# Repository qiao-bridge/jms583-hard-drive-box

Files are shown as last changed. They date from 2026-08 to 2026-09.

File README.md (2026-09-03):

# JMS583 硬盘盒

> 基于 JMS583 主控的 M.2 NVMe 固态硬盘盒开源项目，采用「硬盘盒 + M.2 固态」的组合形式，**顺序读取速度可达 700MB/s**，兼顾大容量与高速读写。




- **嘉立创开源硬件平台**：https://oshwhub.com/qiao_wen/jms583-based-hard-disk-box
- **Gitee 仓库**：https://gitee.com/qiao-wenguo/jms583-hard-drive-box

---

## 目录

- [项目简介](#项目简介)
- [特性](#特性)
- [硬件架构](#硬件架构)
- [实物展示](#实物展示)
  - [整体效果](#整体效果)
  - [速度测试](#速度测试)
- [实物拼装](#实物拼装)
  - [所需材料](#所需材料)
  - [速度测试](#装配步骤)
- [快速开始](#快速开始)
- [固件说明](#固件说明)
  - [JMS583固件](#JMS583固件)
  - [STC8G1K08A固件](#STC8G1K08A固件)
- [目录结构](#目录结构)
- [开源许可](#开源许可)
- [致谢与参考](#致谢与参考)

---

## 项目简介

传统的移动存储介质，容量与速度难以兼得。本项目以 **JMicron JMS583** USB 3.1 Gen 2 转 PCIe/NVMe 桥接芯片为核心，搭配一块 **M.2 固态硬盘**，实现一个：
- **大容量**：支持 NVMe M.2 SSD，轻松扩展到数 TB；
- **高速度**：USB 3.1 Gen 2（10Gbps）接口，实测**顺序读取约 700MB/s**；
- **扩展性**：比成品硬盘盒更灵活，加入stc8g单片驱动内置风扇，便于学习与二次开发。
- **主要面向**：需要大容量高速移动存储的场景。 
>——锅包肉

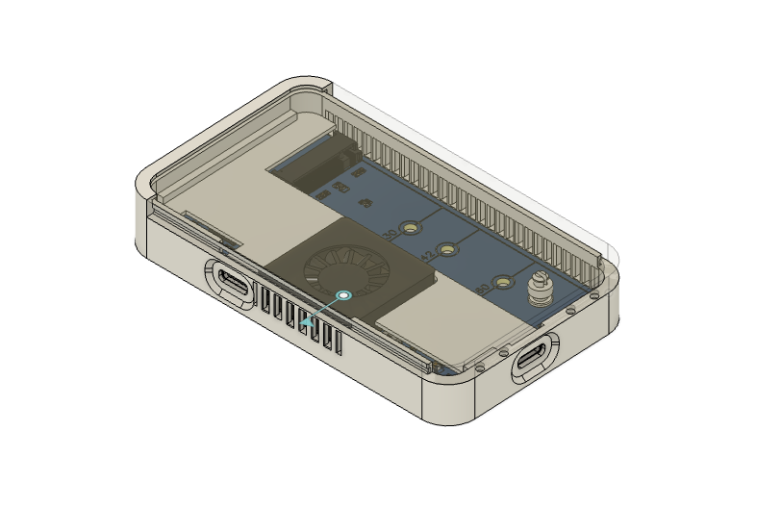
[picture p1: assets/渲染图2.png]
产品整体效果

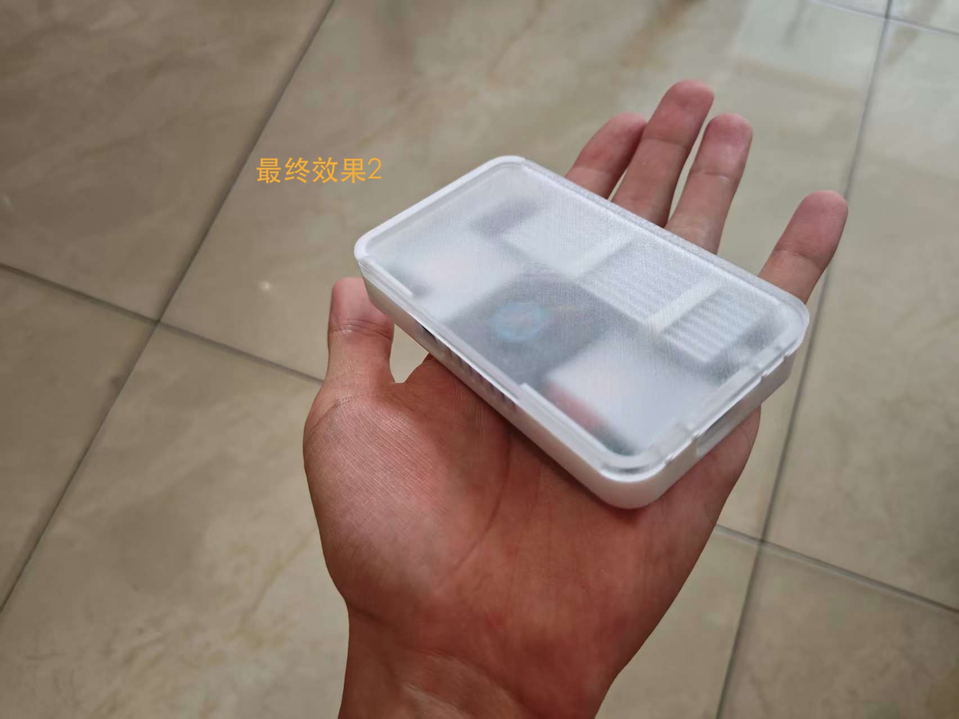
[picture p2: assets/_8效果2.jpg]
成品效果3

> 成品整体效果（PCB + 外壳 + M.2 固态装配完成）。

详见 [特性一览](#特性) 与 [实物展示](#实物展示)。

---

## 特性

- 🚀 **主控芯片**：JMicron JMS583（USB 3.1 Gen 2 to NVMe Bridge）
- 💾 **存储接口**：M.2 M-Key（NVMe）
- 🔌 **上行接口**：USB Type-C（USB 3.1 Gen 2，10Gbps）
- ⚡ **性能**：顺序读取可达 **700MB/s**（受 SSD 与线缆质量影响）
- 🧊 **散热**：PCB 预留散热片，内置涡轮风扇，外壳开散热窗
- 🔧 **固件**：提供JMS583固件与 stc8g的驱动
- 📦 **外壳**：3D 打印，装配即用

---

## 硬件架构

系统由 **USB 接口 → JMS583 桥接 → M.2 固态** 三部分组成，整体框图如下：

```
┌─────────────────────────────────────────────┐
│                 硬盘盒 PCB                    │
│                                             │
│   Type-C (数据) ──► JMS583 ──► M.2 NVMe SSD │
│                        │                    │
│   Type-C (供电) ──► 电源管理                 │
│                                             │
│                    STC8G1K08A ◄── 风扇/LED  │
│                                             │
└─────────────────────────────────────────────┘
```

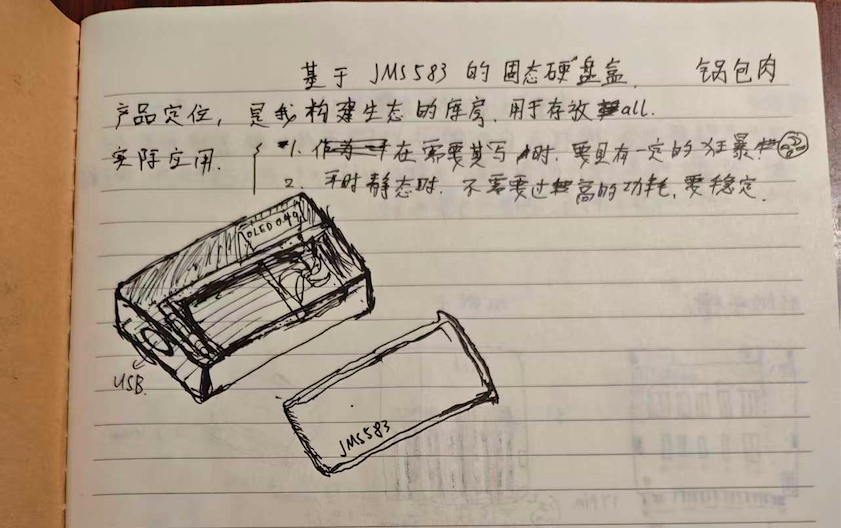
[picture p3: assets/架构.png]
硬件架构图

> 思路结构。

> 详见 [`hardware/`](./hardware) 目录下的原理图、PCB 源文件（如立创EDA）。

---

## 实物展示

### 整体效果
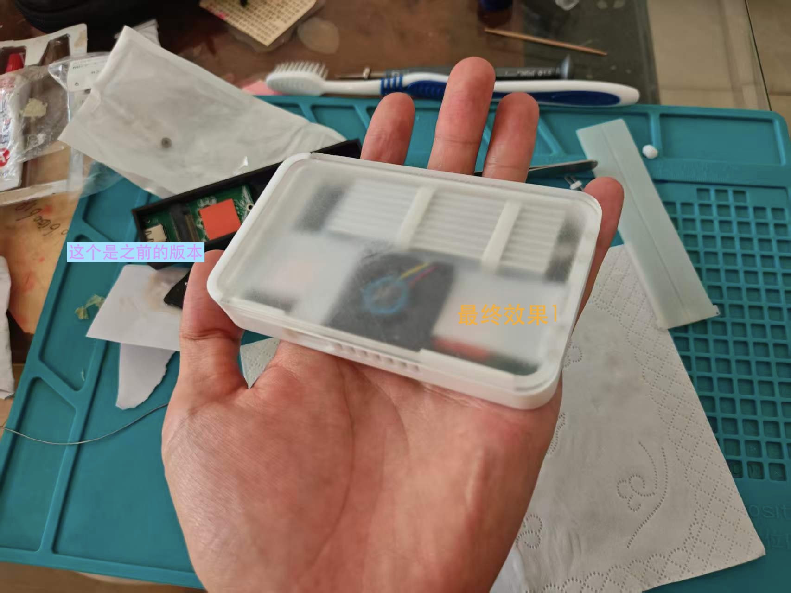
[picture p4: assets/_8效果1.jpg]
成品效果 1

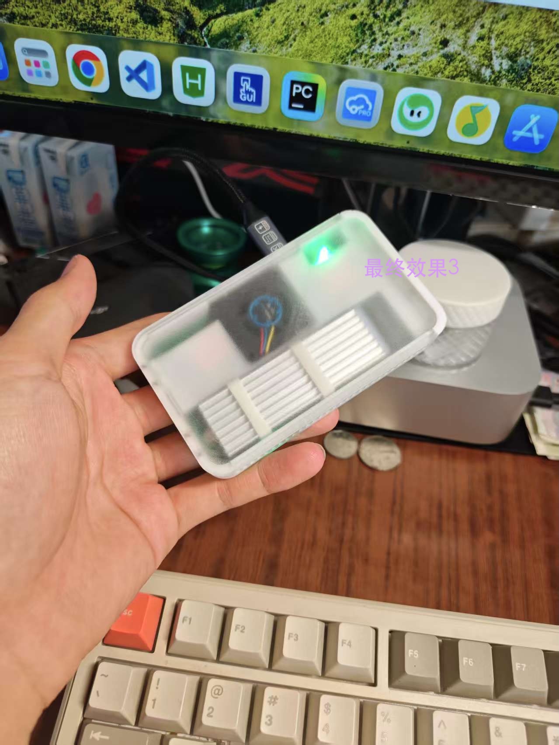
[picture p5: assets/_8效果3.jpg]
成品效果 2


> 分解 / 爆炸动画见 [`分解效果.mp4`](assets/分解效果.mp4)。

### 速度测试

在 Windows / macOS 下实测，顺序读取可达约 **700MB/s**：

#### CrystalDiskMark（Windows）

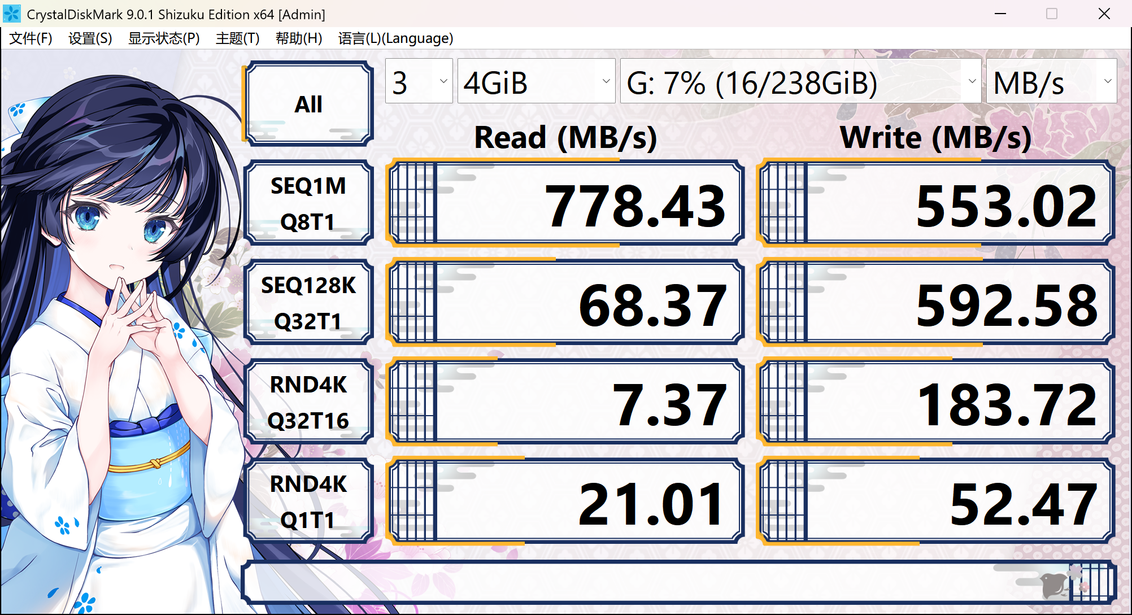
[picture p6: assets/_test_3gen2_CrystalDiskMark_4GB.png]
CrystalDiskMark USB3 Gen2 4GB 测试

> USB 3.1 Gen 2 模式下 4GB 测试块结果, 顺序读取约 700MB/s。

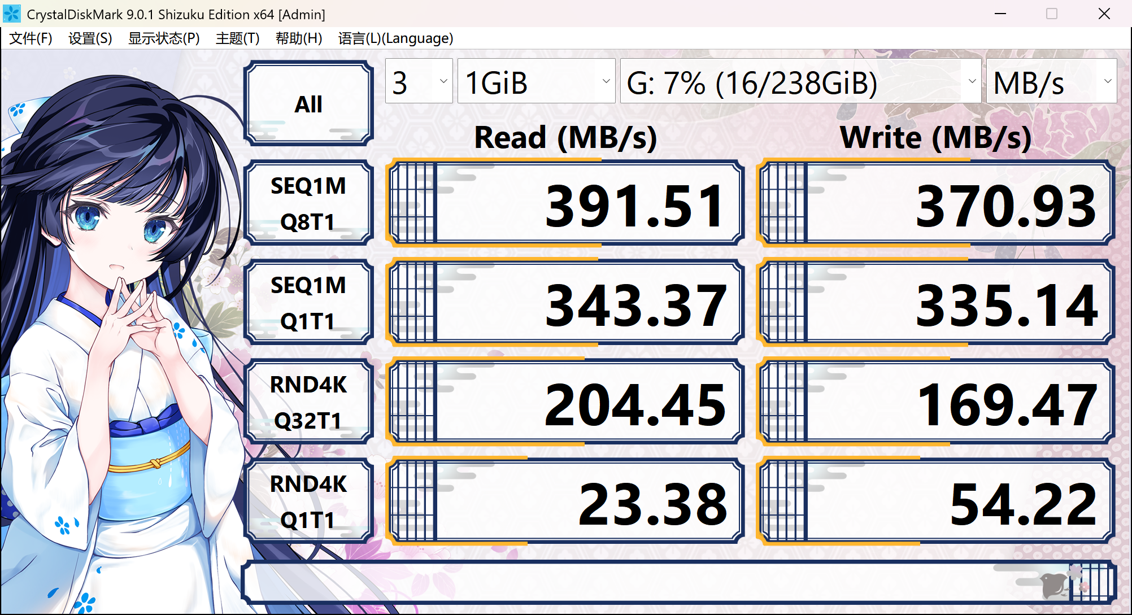
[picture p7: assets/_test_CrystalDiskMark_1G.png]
CrystalDiskMark 1GB 测试

> 1GB 测试块，顺序读取约 400MB/s。

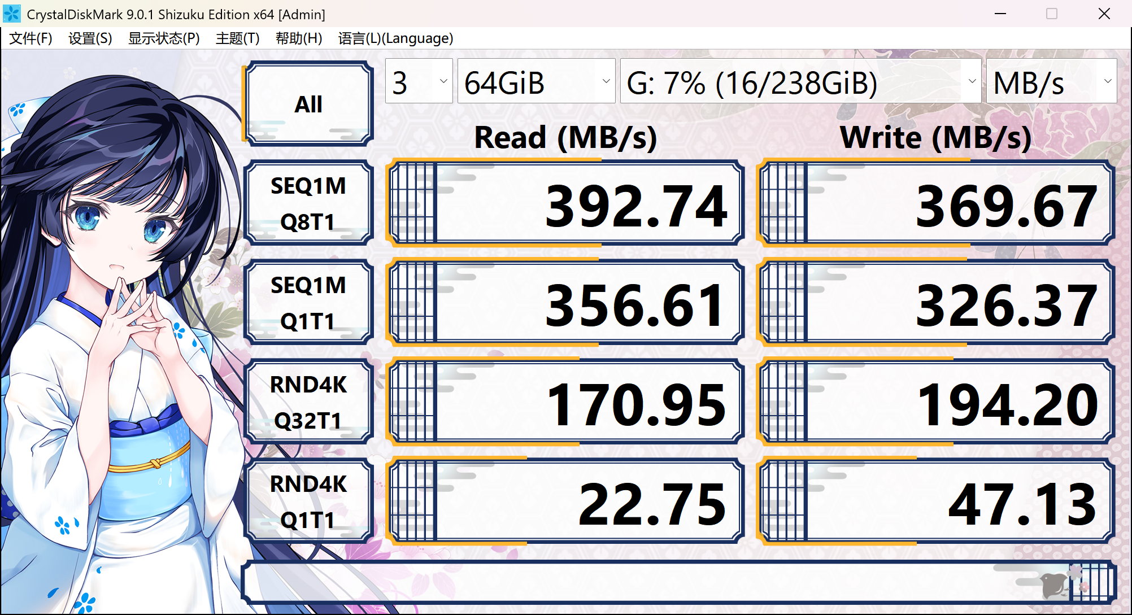
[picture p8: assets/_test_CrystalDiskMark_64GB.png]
CrystalDiskMark 64GB 测试

> 64GB 大文件测试，验证持续读写稳定性。

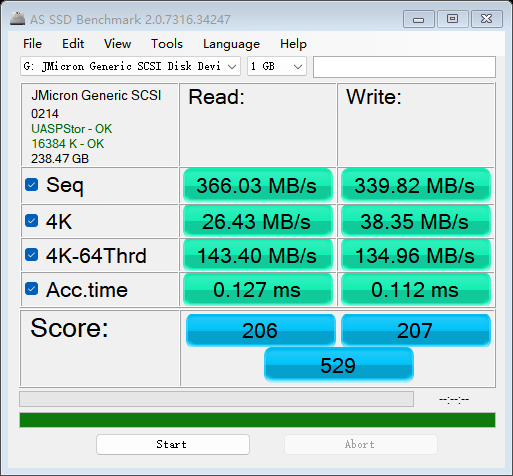
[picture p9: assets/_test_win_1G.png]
SSD benchmark 1G

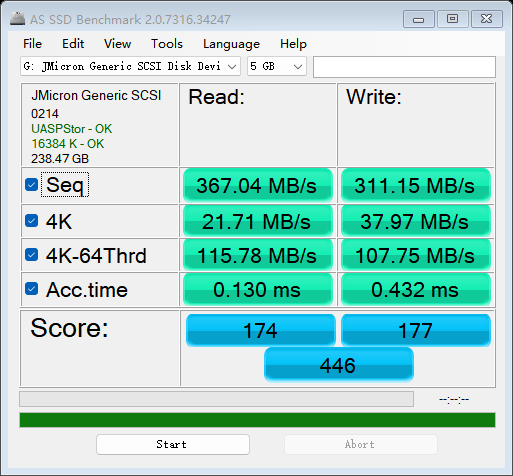
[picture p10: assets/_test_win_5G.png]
SSD benchmark 5G

> benchmark，验证持续读写稳定性。

#### Blackmagic Disk Speed Test（macOS）

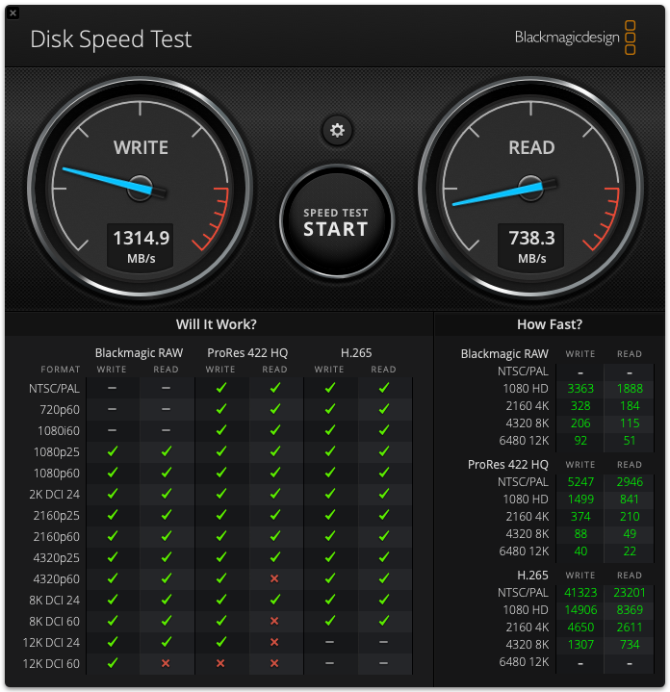
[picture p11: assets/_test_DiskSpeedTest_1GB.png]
DiskSpeedTest 1GB

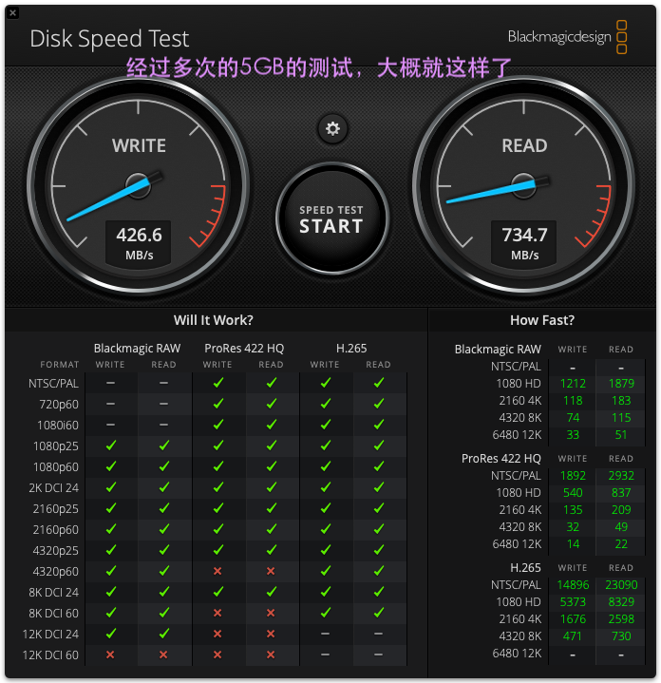
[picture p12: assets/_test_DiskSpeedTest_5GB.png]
DiskSpeedTest 5GB

> macOS 下使用 Blackmagic Disk Speed Test 测试（1GB / 5GB 测试文件）。

#### macOS 下实际文件拷贝测试

- 读取 17GB 文件实测约 30 秒：[`_test_mac实际读取17GB文件测试_大概过30s.mov`](assets/_test_mac实际读取17GB文件测试_大概过30s.mov)
- 写入 17GB 文件实测约 52 秒：[`_test_mac实际写入17GB文件测试_大概过52s.mov`](assets/_test_mac实际写入17GB文件测试_大概过52s.mov)

> 实际数值以你的 SSD 型号、线缆质量与主机接口为准。

---

## 实物拼装

### 所需材料

- [ ] 焊接好的 PCB（见 [焊接风扇](#焊接风扇)）
- [ ] JMS583 主控及外围元器件
- [ ] M.2 NVMe 固态硬盘一块
- [ ] USB Type-C 数据线（**需支持 USB 3.1 Gen 2 / 10Gbps**，普通 2.0 线缆无法达到标称速度）
- [ ] 外壳
- [ ] 导热垫 / 散热片

### 装配步骤
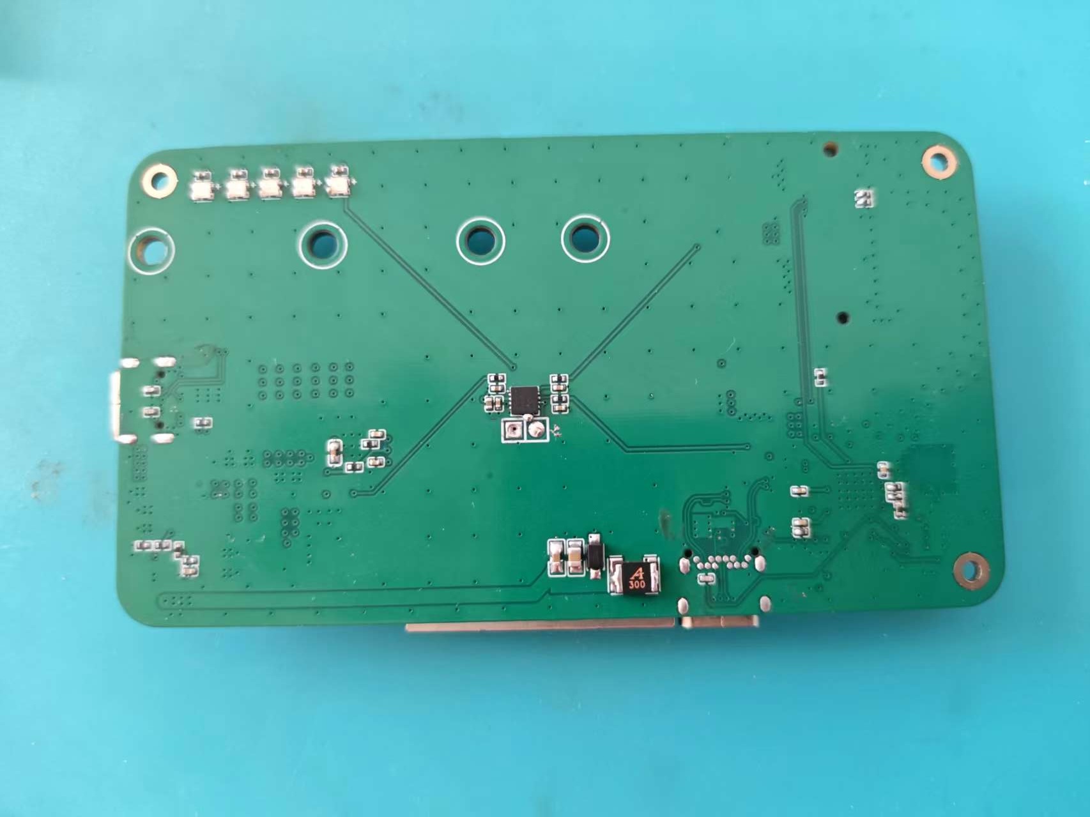
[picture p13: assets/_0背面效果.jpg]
背面效果


> 装配流程分解：

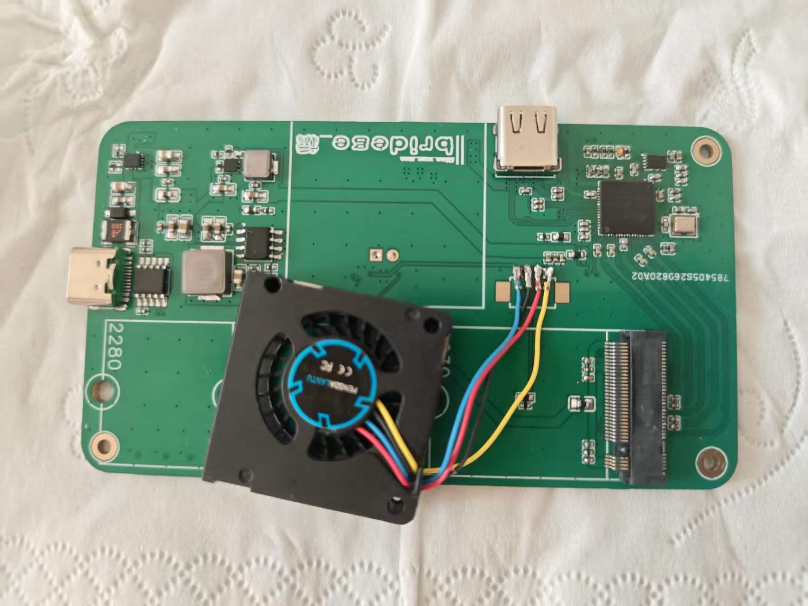
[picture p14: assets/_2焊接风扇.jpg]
焊接风扇

> 焊接风扇与散热相关元件。

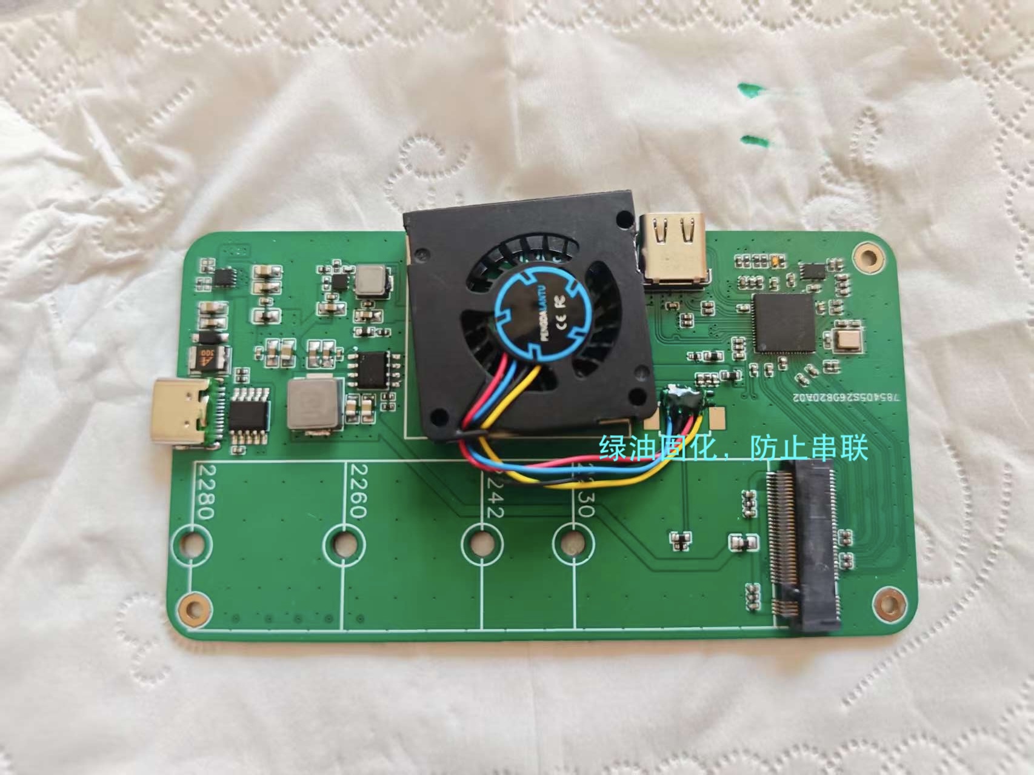
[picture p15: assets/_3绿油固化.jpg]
绿油固化

> PCB 绿油固化处理。

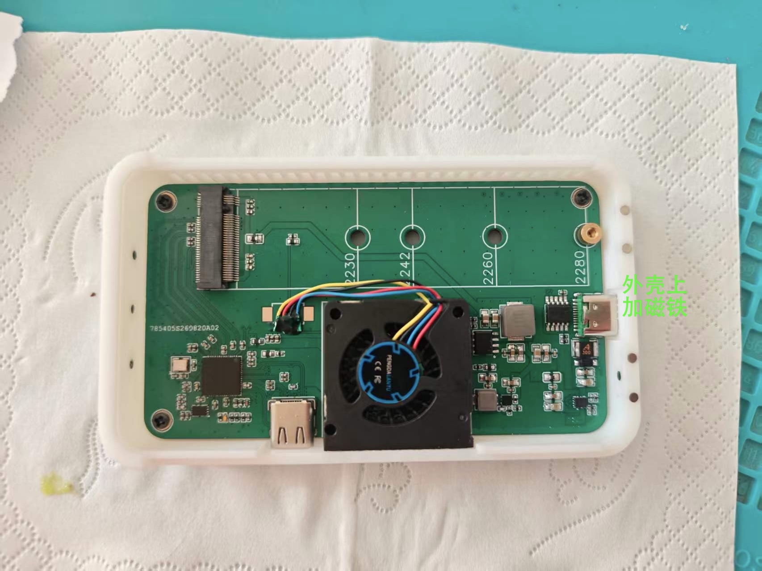
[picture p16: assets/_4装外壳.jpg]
装入外壳

> 将 PCB 装入外壳并固定。

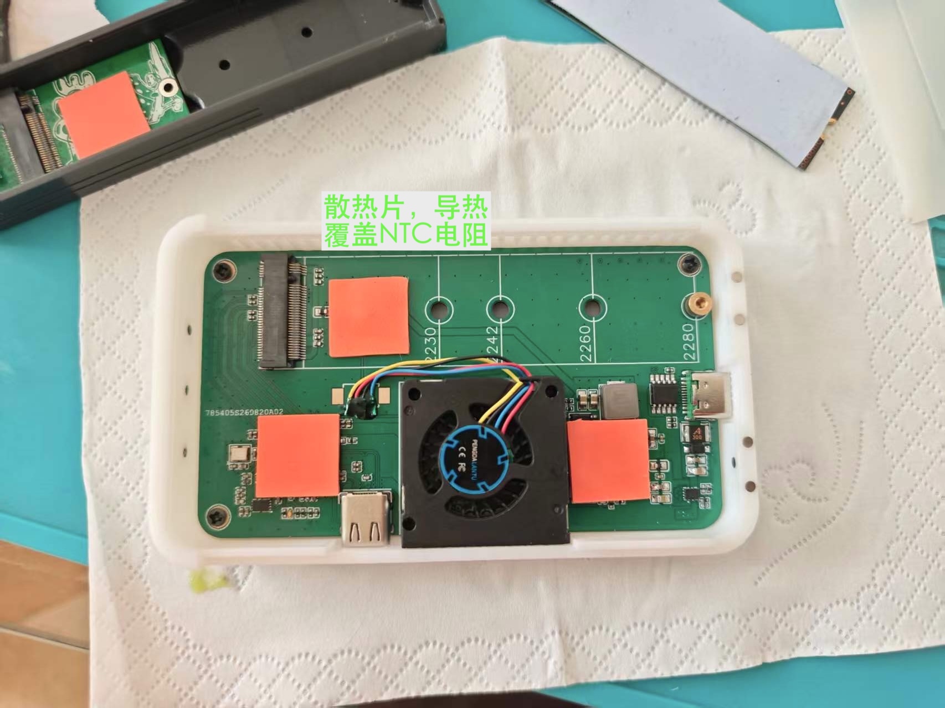
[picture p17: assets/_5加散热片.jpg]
安装散热片

> 在主控 / 颗粒面贴导热垫并加装散热片。

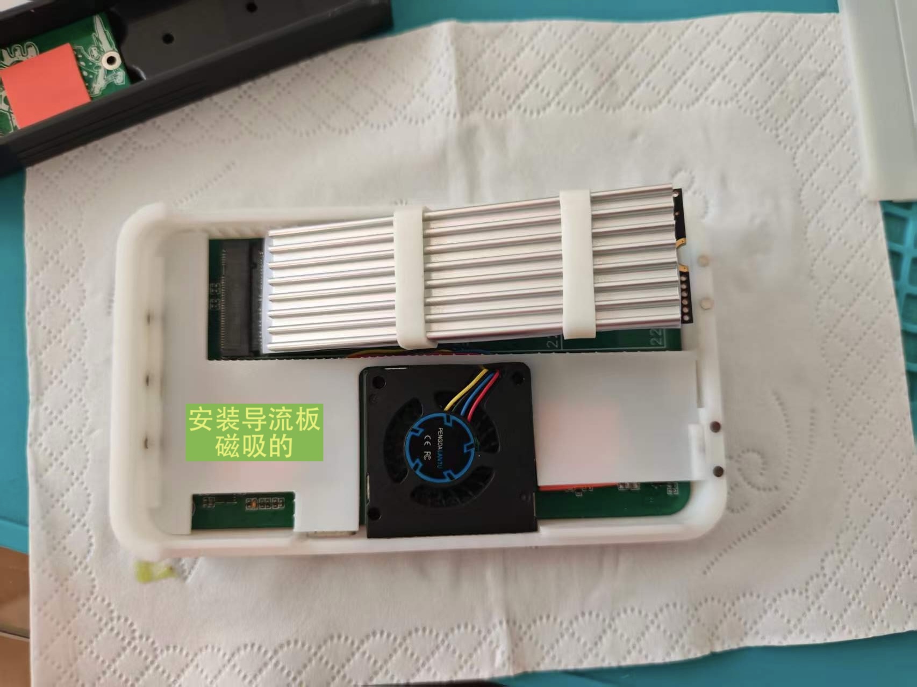
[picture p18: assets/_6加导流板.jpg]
加装导流板

> 加装导流板，优化风道。

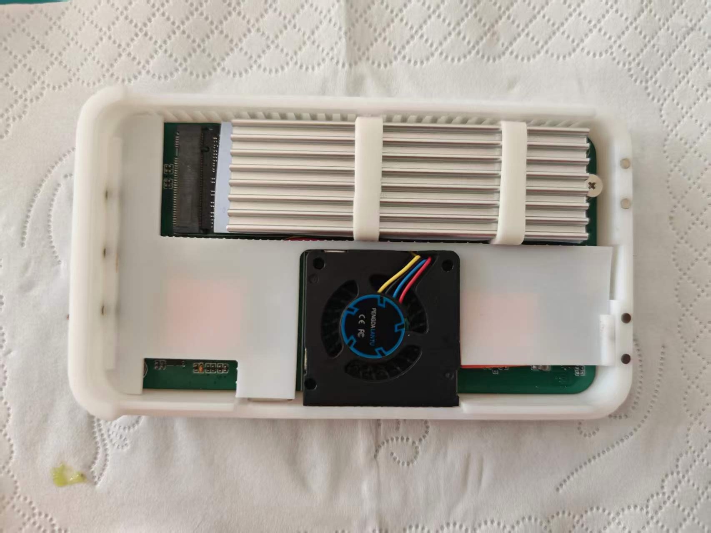
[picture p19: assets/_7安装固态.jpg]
安装固态

> 安装 M.2 固态硬盘。

---

## 快速开始

### 制作 PCB

见 [`hardware/`](./hardware) 目录，包含原理图、PCB 源文件与 Gerber。推荐使用嘉立创等平台打样：

1. 直接打印Gerber文件；
2. 按默认工艺下单（板厚 1.6mm，沉金或喷锡均可）；
3. 收到板子后按 BOM 焊接。

### 打印 / 制作外壳

见 [`enclosure/`](./enclosure) 目录，包含可打印文件stl以及源文件。

- 3D 打印建议：下壳和导流板材料随意，上盖使用半透明（8001）或透明；
- 装配时先放安装m2*1的磁铁，用螺丝（m2*3或M2*4）固定pcb，最后是上盖。
- 外壳模型渲染见 [项目简介](#项目简介)（[`渲染图.PNG`](assets/渲染图2.PNG)），成品效果见 [实物展示](#实物展示)（[`_8效果1.jpg`](assets/_8效果1.jpg) 等）。

### 焊接元器件

- 推荐使用**热风枪 + 锡膏**焊接 JMS583（QFN）、M.2接口、typec、小元件；
- Type-C 等密脚元件可用烙铁 + 助焊剂；
- 焊接完成后**先检查短路**（尤其电源与地），再上电。

---

## 固件说明

> 本项目包含 **两套固件**，分别对应两个主控：
> 1. **JMS583** 桥接芯片固件（USB ↔ NVMe 桥接逻辑）
> 2. **STC8G1K08A** 单片机固件（风扇 / 呼吸灯 / adc等控制逻辑）

### JMS583固件
- **作用**：实现 USB 3.2 Gen 2 与 PCIe NVMe 之间的协议桥接。
- **文件**：见仓库 `firmware/jms583/` 目录。
- **升级方式**：通常通过厂商工具FwUpdateTool.exe `firmware/jms583/tools`通过 USB 接口在线升级。
- **注意**：
  - 在刷写的时候看看有没有Flash的信息，jms583支持挺多厂商的，如果没有flash的信息，烧录会是比啊，检查是不是焊接问题（包括那个QFN的焊接）或者是换个芯片。
  - 固件升级过程与本仓库的 STC8G1K08A 烧录是**两个独立流程**，请勿混淆。

### STC8G1K08A固件
- **作用**：控制散热风扇、WS2812呼吸灯、adc等辅助逻辑。
- **开发环境**：Keil C51。
- **烧录方式**：通过串口（UART）连接 STC8G1K08A 的 **P3.0 (RxD) / P3.1 (TxD)** 引脚，使用 STC-ISP 工具烧录。
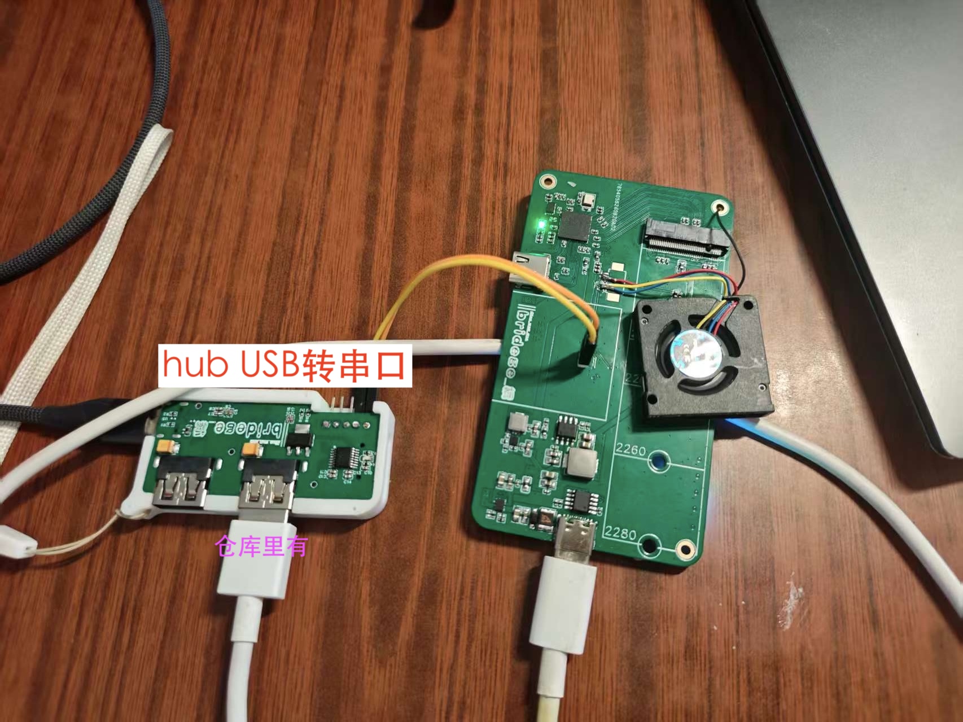
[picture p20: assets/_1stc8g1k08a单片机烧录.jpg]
STC8G1K08A 烧录
- **烧录要点**：stc8g的供电和串口的供电时同一路，见

---

## 目录结构

```
jms583硬盘盒/
├── Datasheet/   # JMS583 等芯片数据手册 (Datasheet)
├── assets/      # README 引用的图片资源（本文件所用配图）
├── docs/        # 补充文档（说明、规格、测试记录等）
├── enclosure/   # 外壳 3D 模型 / 加工图纸
├── firmware/    # 两种固件
├── hardware/    # 原理图、PCB 源文件与 Gerber
├── LICENSE      # GPL-3.0 许可证
└── README.md    # 本文档
```

---

## 许可证

本项目基于 **GNU General Public License v3.0** 开源，详见 [`LICENSE`](./LICENSE) 文件。

> 硬件设计（原理图、PCB）遵循相同的开源许可，允许个人与商业使用，但需保留署名并按 GPL 开源衍生作品。

## 致谢与参考

- [JMicron JMS583 产品页](https://www.jmicron.com/)
- [嘉立创开源硬件平台 - 本项目](https://oshwhub.com/qiao_wen/jms583-based-hard-disk-box)

---

> 本文档随项目持续更新。如发现错误或有改进建议，欢迎提 Issue / PR。
如发现错误或有改进建议，欢迎提 Issue / PR。

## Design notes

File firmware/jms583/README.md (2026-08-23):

###改固件使用的来自于https://oshwhub.com/aknice/jms583-demo

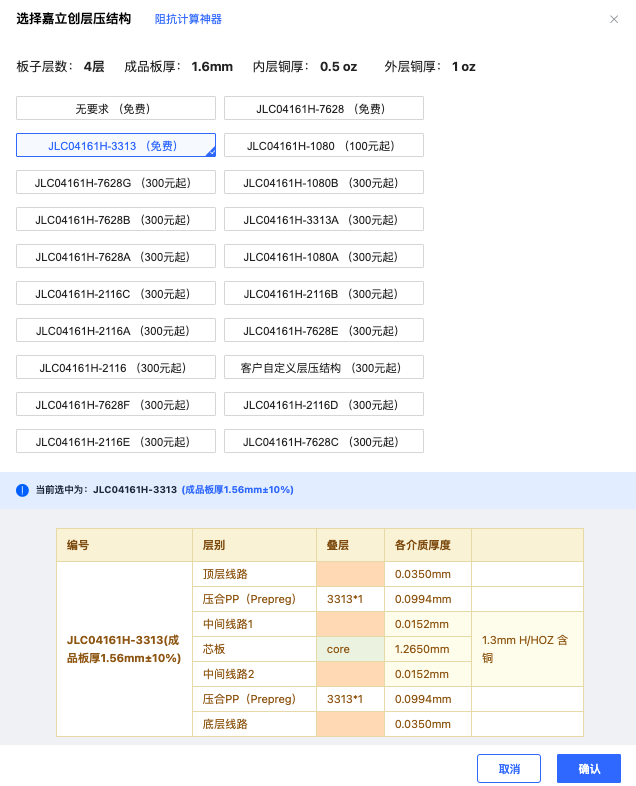
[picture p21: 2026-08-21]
docs/嘉立创压层选择.png

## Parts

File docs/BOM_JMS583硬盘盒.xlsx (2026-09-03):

No. | Quantity | Comment | Designator | Footprint | Value | Manufacturer Part | Manufacturer | Supplier Part | Supplier
1 | 45 | 100nF | C1,C2,C3,C6,C9,C15,C18,C22,C23,C26,C30,C34,C35,C36,C37,C38,C41,C42,C46,C48,C50,C51,C54,C55,C56,C57,C60,C61,C62,C63,C64,C67,C70,C74,C75,C77,C81,C82,C83,C84,C85,C86,C87,C88,C89 | C0402 | 100nF | HGC0402R5106M100NTEJ | Chinocera(华瓷) |  | LCSC
2 | 6 | 22uF | C4,C11,C13,C16,C32,C33 | C0805 | 22uF | HGC0805R5226M350NSLJ | Chinocera(华瓷) | C22367832 | LCSC
3 | 8 | 10uF | C5,C12,C14,C17,C24,C27,C28,C29 | C0805 | 10uF | HGC0805R5226M350NSLJ | Chinocera(华瓷) |  | LCSC
4 | 4 | 330pF | C7,C8,C19,C20 | C0402 | 330pF | HGC0402R5106M100NTEJ | Chinocera(华瓷) |  | LCSC
5 | 10 | 1uF | C10,C40,C43,C44,C47,C49,C66,C69,C73,C79 | C0402 | 1uF | HGC0402R5106M100NTEJ | Chinocera(华瓷) |  | LCSC
6 | 1 | 10nF | C21 | C0603 | 10nF | HGC0603R5106M350NTHJ | Chinocera(华瓷) |  | LCSC
7 | 1 | 22pF | C25 | C0402 | 22pF | HGC0402R5106M100NTEJ | Chinocera(华瓷) |  | LCSC
8 | 1 | 3.9nF | C31 | C0402 | 3.9nF | HGC0402R5106M100NTEJ | Chinocera(华瓷) |  | LCSC
9 | 8 | 10uF | C39,C45,C65,C68,C71,C72,C76,C80 | C0402 | 10uF | HGC0402R5106M100NTEJ | Chinocera(华瓷) |  | LCSC
10 | 4 | 220nF | C52,C53,C58,C59 | C0402 | 220nF | HGC0402R5106M100NTEJ | Chinocera(华瓷) |  | LCSC
11 | 1 | 15pF | C78 | C0402 | 15pF | CC0402JRNPO9BN200 | YAGEO(国巨) |  | LCSC
12 | 1 | M-key 3.2H（m.2固态接口）91302-32-067RDM | CN1 | CONN-SMD_91302-32-067RDM |  | 91302-32-067RDM | UMaxconn(友贸) | C1509730 | LCSC
13 | 1 | （可以不用，手焊，风扇接口座子，）SH-1.25-4AWT | CN2 | CONN-SMD_SH-1.25-4AWT |  | SH-1.25-4AWT | 深海电子 | C53260987 | LCSC
14 | 2 | （双向tvs）SMF5.0CA | D1,D2 | SOD-123FL_L2.7-W1.8-LS3.8-BI |  | SMF5.0CA | R+O(宏嘉诚) | C19077498 | LCSC
15 | 2 | （保险丝保持3A跳闸4A）SMD1812-300-12 | F1,F2 | F1812 |  | SMD1812-300-12 | R+O(宏嘉诚) | C46641166 | LCSC
16 | 1 | （磁珠4A）BLM21PG300SN1D | FB1 | L0805 | 30Ω | BLM21PG300SN1D | muRata(村田) | C16903 | LCSC
17 | 1 | （烧录排针2.54）A2541WV-2P | H1 | HDR-TH_P2.54-H-M_A2541WV-2P |  | A2541WV-2P | CJT(长江连接器) | C225477 | LCSC
18 | 1 | 2.2uH | L1 | IND-SMD_L4.4-W4.2 | 2.2uH | FXL0420-2R2-M | cjiang(长江微电) | C167206 | LCSC
19 | 1 | 10uH | L2 | IND-SMD_L7.3-W6.8 | 10uH | FXL0630-100-M | cjiang(长江微电) | C167223 | LCSC
20 | 1 | (磁珠2A）CBM160808U121T | L3 | L0603 |  | CBM160808U121T | FH(风华) | C62708 | LCSC
21 | 1 | (磁珠4A）CBM201209U121T | L4 | L0805 |  | CBM201209U121T | FH(风华) | C93624 | LCSC
22 | 1 | led_0402 | LED1 | LED-SMD_L1.0-W0.5_FC-F1005UGK |  | NCD0402G1 | 国星光电 | C130723 | LCSC
23 | 5 | WS2812B-2020-V6 | LED2,LED3,LED4,LED5,LED6 | LED-SMD_4P-L2.2-W2.0-P1.00_WS2815C-2020-4P |  | WS2812B-2020-V6 | worldsemi | C52917434 | LCSC
24 | 2 | 20kΩ | R1,R2 | R0402 | 20kΩ | THC02H1002BT | FH(风华) |  | LCSC
25 | 1 | 29.8kΩ | R3 | R0402 | 29.8kΩ | THC02H1002BT | FH(风华) |  | LCSC
26 | 5 | 100kΩ | R4,R11,R12,R14,R25 | R0402 | 100kΩ | THC02H1002BT | FH(风华) |  | LCSC
27 | 3 | 5kΩ | R5,R6,R8 | R0402 | 5kΩ | THC02H1002BT | FH(风华) |  | LCSC
28 | 9 | 10kΩ | R7,R18,R20,R32,R33,R34,R35,R36,R37 | R0402 | 10kΩ | THC02H1002BT | FH(风华) |  | LCSC
29 | 2 | 2kΩ | R9,R10 | R0402 | 2kΩ | THC02H1002BT | FH(风华) |  | LCSC
30 | 1 | 91kΩ | R13 | R0402 | 91kΩ | THC02H1002BT | FH(风华) |  | LCSC
31 | 1 | 6.8kΩ | R15 | R0402 | 6.8kΩ | THC02H1002BT | FH(风华) |  | LCSC
32 | 1 | 120kΩ | R16 | R0402 | 120kΩ | THC02H1002BT | FH(风华) |  | LCSC
33 | 1 | 26.1kΩ | R17 | R0402 | 26.1kΩ | THC02H1002BT | FH(风华) |  | LCSC
34 | 1 | 5.1kΩ | R19 | R0402 | 5.1kΩ | THC02H1002BT | FH(风华) |  | LCSC
35 | 1 | 12kΩ | R21 | R0402 | 12kΩ | THC02H1002BT | FH(风华) |  | LCSC
36 | 2 | 49.9Ω | R22,R23 | R0402 | 49.9Ω | THC02H1002BT | FH(风华) |  | LCSC
37 | 1 | 510kΩ | R24 | R0402 | 510kΩ | THC02H1002BT | FH(风华) |  | LCSC
38 | 1 | 200Ω | R26 | R0402 | 200Ω | THC02H1002BT | FH(风华) |  | LCSC
39 | 1 | 4.7kΩ | R27 | R0402 | 4.7kΩ | THC02H1002BT | FH(风华) |  | LCSC
40 | 1 | 200kΩ | R28 | R0402 | 200kΩ | THC02H1002BT | FH(风华) |  | LCSC
41 | 3 | (NTC热敏电阻)HNTC0603-104F3950FB | R29,R30,R31 | R0603 |  | HNTC0603-104F3950FB | R+O(宏嘉诚) | C49247668 | LCSC
42 | 1 | TPS2121RUXR | U1 | VQFN-HR-12_L2.5-W2.0-P0.50-BL |  | TPS2121RUXR | TI(德州仪器) | C485916 | LCSC
43 | 1 | CH224A | U2 | ESSOP-10_L4.9-W3.9-P1.0-LS6.0-TL-EP |  | CH224A | WCH(南京沁恒) | C42459160 | LCSC
44 | 1 | AP2953AS8PRG | U3 | ESOP-8_L4.9-W3.9-P1.27-LS6.0-BL-EP |  | AP2953AS8PRG | chipown(芯朋微电子) | C130334 | LCSC
45 | 1 | AP3428DNTR-G1 | U4 | U-DFN2020-6_L2.0-W2.0-P0.65-BL-EP-2 |  | AP3428DNTR-G1 | DIODES(美台) | C698228 | LCSC
46 | 1 | JMS583 | U5 | QFN-64_L8.0-W8.0-P0.40-TL-EP4.5 |  | JMS583 |  | C9900032798 | LCSC
47 | 1 | W25Q80DVUXIE | U6 | USON-8_L3.0-W2.0-P0.50-BL-EP_GD25QXX |  | W25Q80DVUXIE | Winbond(华邦) | C401667 | LCSC
49 | 1 | STC8G1K08A-36I-DFN8 | U11 | DFN-8_L3.0-W3.0-P0.50-BL-EP |  | STC8G1K08A-36I-DFN8 | STC | C915664 | LCSC
50 | 3 | M2螺丝：M2*3 | U12,U13,U14 | M2螺丝孔 |  |  |  |  | LCSC
51 | 1 | TYPE-C 24P QCHT | USB1 | TYPE-C-SMD_TYPE-C-24P-QCHT |  | TYPE-C 24P QCHT | SHOU HAN(首韩) | C456013 | LCSC
52 | 1 | KH-TYPE-C-16P | USB2 | USB-C-SMD_KH-TYPE-C-16P |  | KH-TYPE-C-16P | kinghelm(金航标) | C709357 | LCSC
53 | 1 | 25MHz | X1 | OSC-SMD_4P-L3.2-W2.5-BL | 25MHz | OT322525MJBA4SL | YXC(扬兴晶振) | C669088 | LCSC
54 | 最少20个，淘宝一起买 |  | 型号：直径2mm，厚度1mm

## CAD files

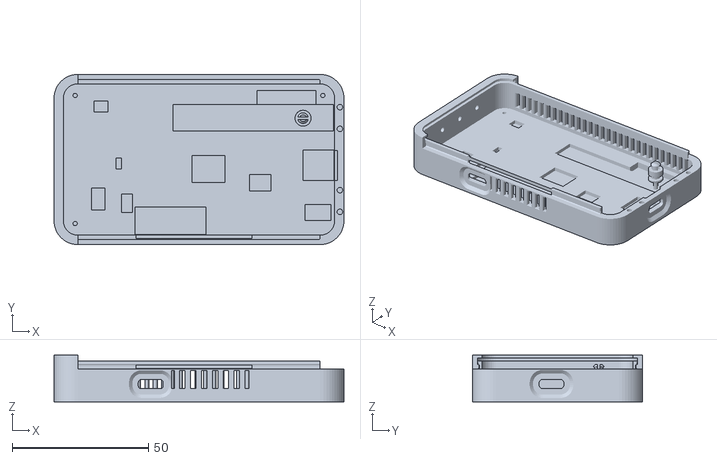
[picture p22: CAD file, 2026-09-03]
enclosure/print/下壳.stl
106.5 x 62.5 x 17.1

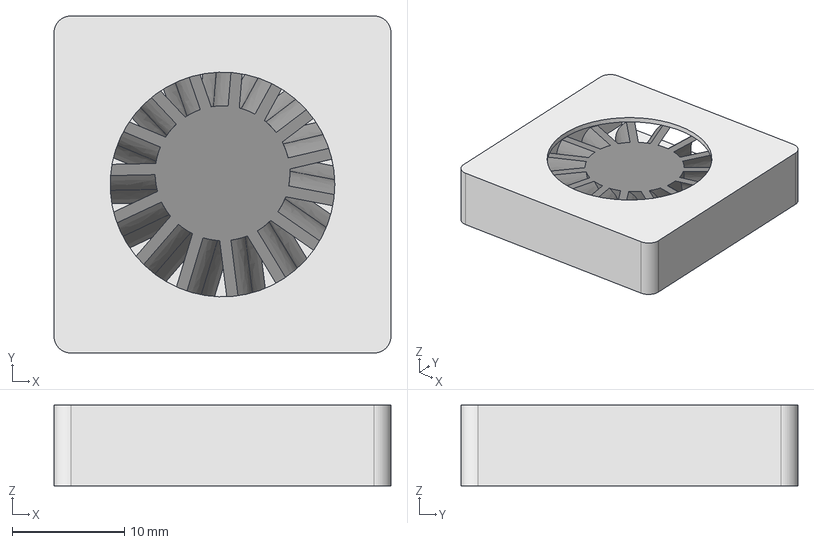
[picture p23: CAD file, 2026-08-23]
enclosure/source/3007涡轮风扇模型.step
30.0 x 30.0 x 7.20 mm
扇叶
涡轮风扇外壳

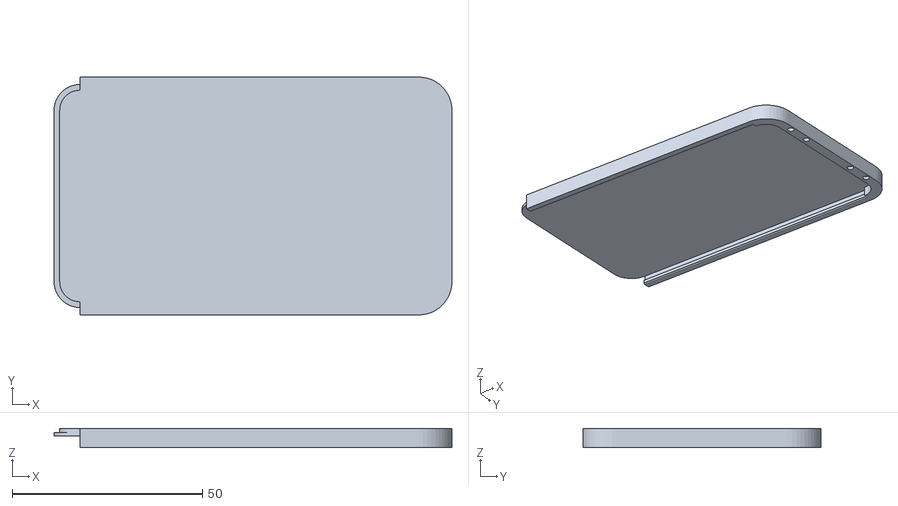
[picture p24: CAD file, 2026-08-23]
enclosure/print/上盖.stl
104.5 x 62.5 x 5.00

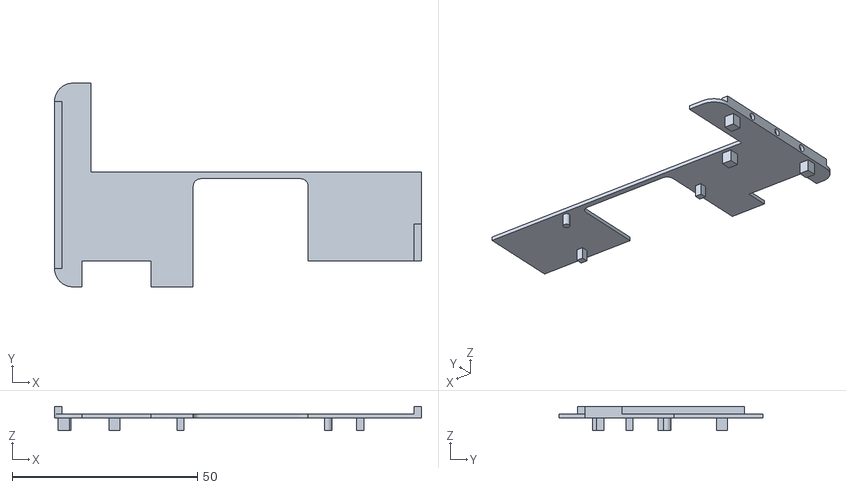
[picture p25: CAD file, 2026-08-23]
enclosure/print/导流板.stl
99.0 x 55.0 x 6.50

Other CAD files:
firmware/stc8g1k08a/project/Objects/main.obj
firmware/stc8g1k08a/project/Objects/stc8g_ws2812.obj
firmware/stc8g1k08a/project/Objects/stc8g_ntc_table.obj
firmware/stc8g1k08a/project/Objects/stc8g_delay.obj
firmware/stc8g1k08a/project/Objects/STARTUP.obj
firmware/stc8g1k08a/project/Objects/stc8g_gpio.obj
firmware/stc8g1k08a/project/Objects/stc8g_uart.obj
firmware/stc8g1k08a/project/Objects/stc8g_timer_pwm.obj
firmware/stc8g1k08a/project/Objects/stc8g_adc.obj
firmware/stc8g1k08a/project/Objects/stc8g_key.obj
firmware/stc8g1k08a/project/Objects/stc8g_pwm.obj
enclosure/source/JMS583硬盘盒外壳.f3z

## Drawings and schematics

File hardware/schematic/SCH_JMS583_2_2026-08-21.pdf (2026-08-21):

GND A12 RX2+ A11 RX2- A10 VBUS A9 SBU1 A8 D- A7 D+ A6 CC1 A5 VBUS A4 TX1- A3 TX1+ A2 GND A1

GND | GND

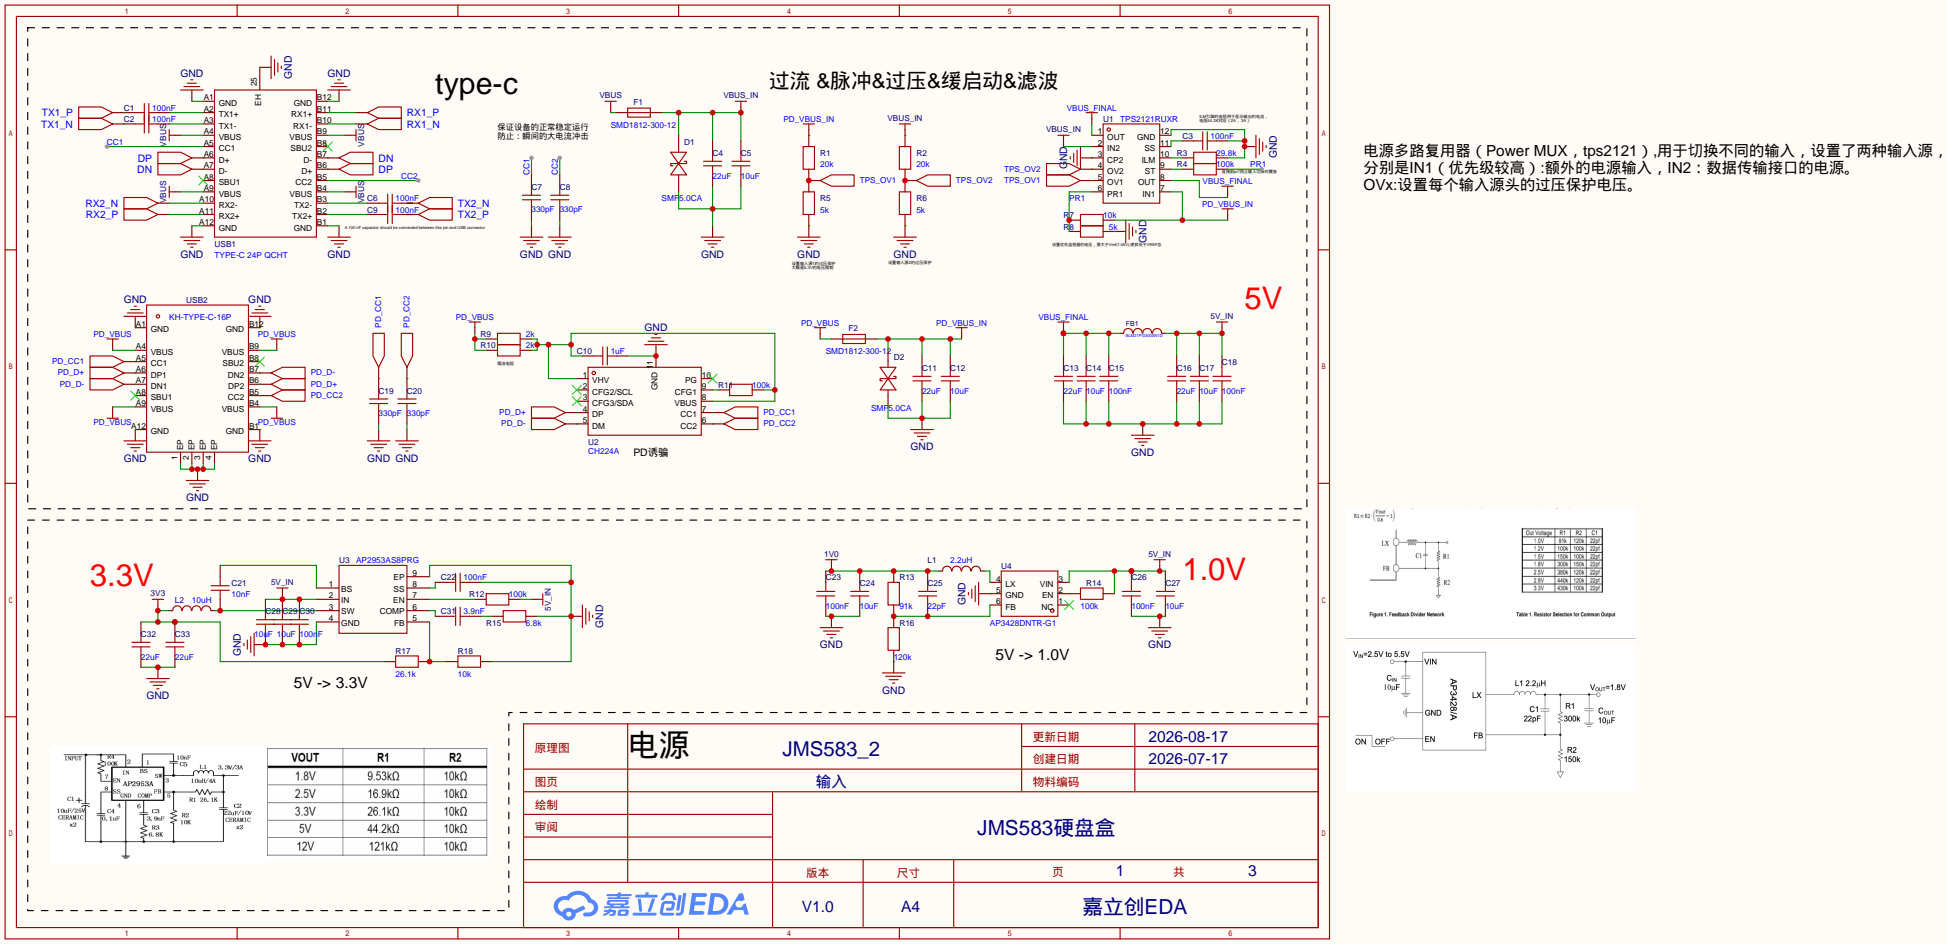
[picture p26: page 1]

过流 &脉冲&过压&缓启动&滤波

电源多路复用器（Power MUX，tps2121）,用于切换不同的输入，设置了两种输入源，
分别是IN1（优先级较高）:额外的电源输入，IN2：数据传输接口的电源。
OVx:设置每个输入源头的过压保护电压。

A 100 nF capacitor should be connected between this pin and USB connector

VCCO 32 P_AVDDL 33 P_RXN1 34 P_RXP1 35 P_AVDDL 36 P_TXN1 37 P_TXP1 38 REXT 39 P_AVDDL 40 P_RXN0 41 P_RXP0 42 P_AVDDL 43 P_TXN0 44 P_TXP0 45 C_AVDDL 46 P_CLKN 47 P_CLKP 48 P_AVDDL 49 XIN 50 XOUT 51 XAVDDH 52 VCCK 53 P_RSTN 54 P_CLKREQN 55 VCCO 56 GPIO12 57 MODE0/GPIO11 58 MODE1/GPIO10 59 TME 60 CC2 61 CC1 62 GND 63 LXO 64 EP 65

### GND

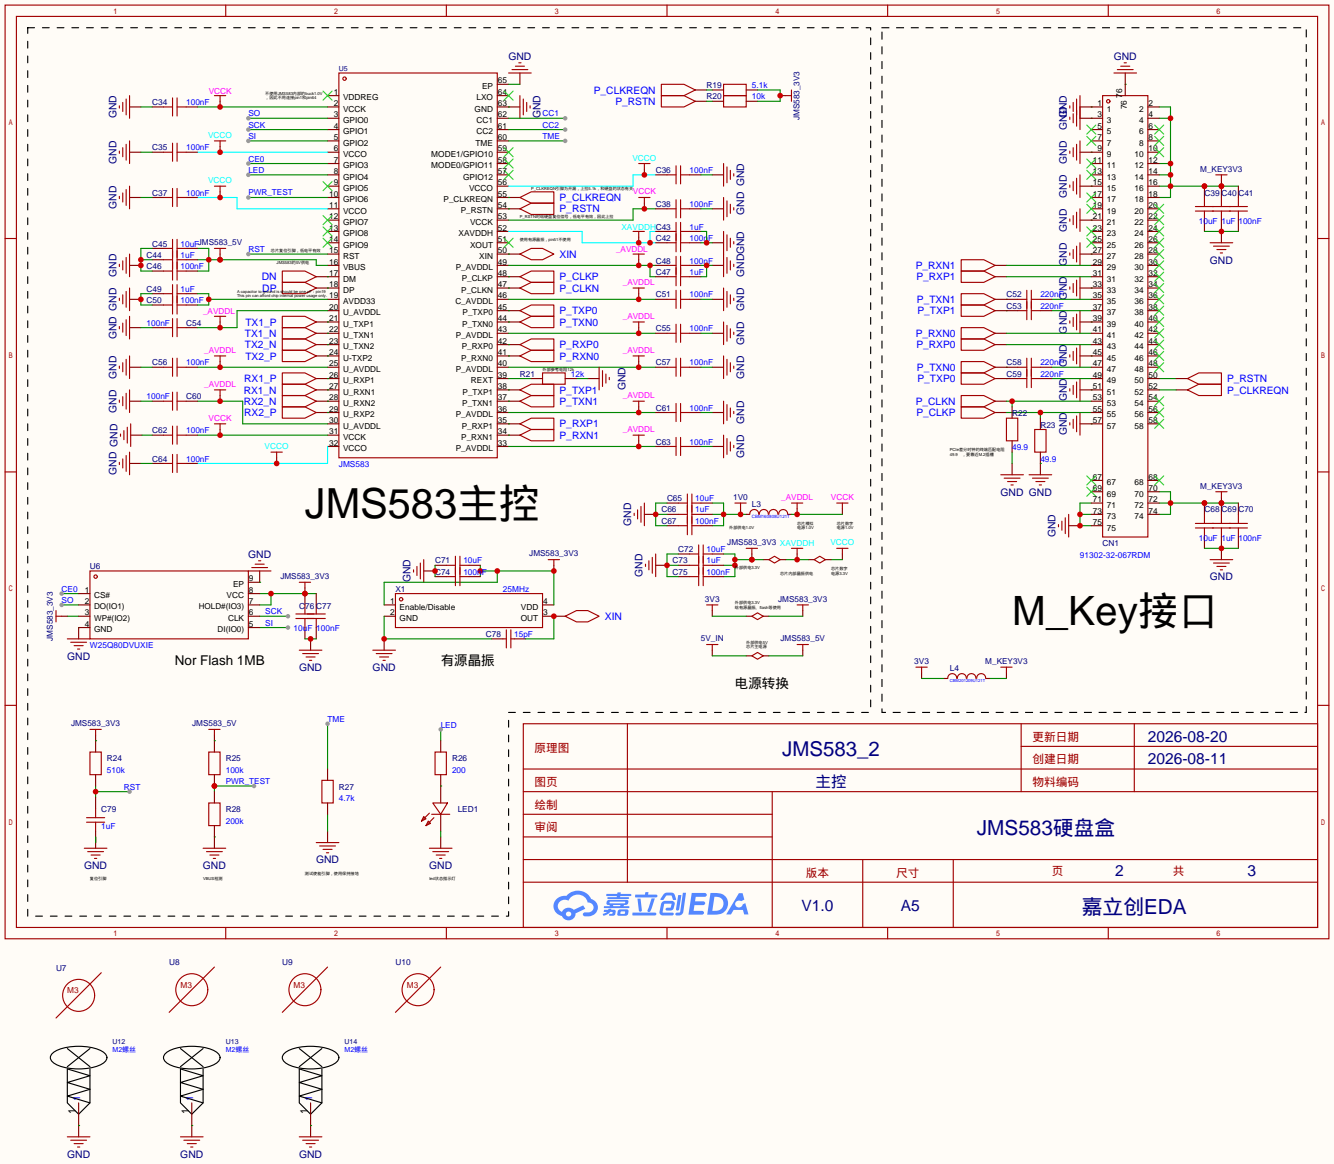
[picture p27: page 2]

GND GND GND GND

C66 | 1uF 100nF
C67

GND | GND

### GND

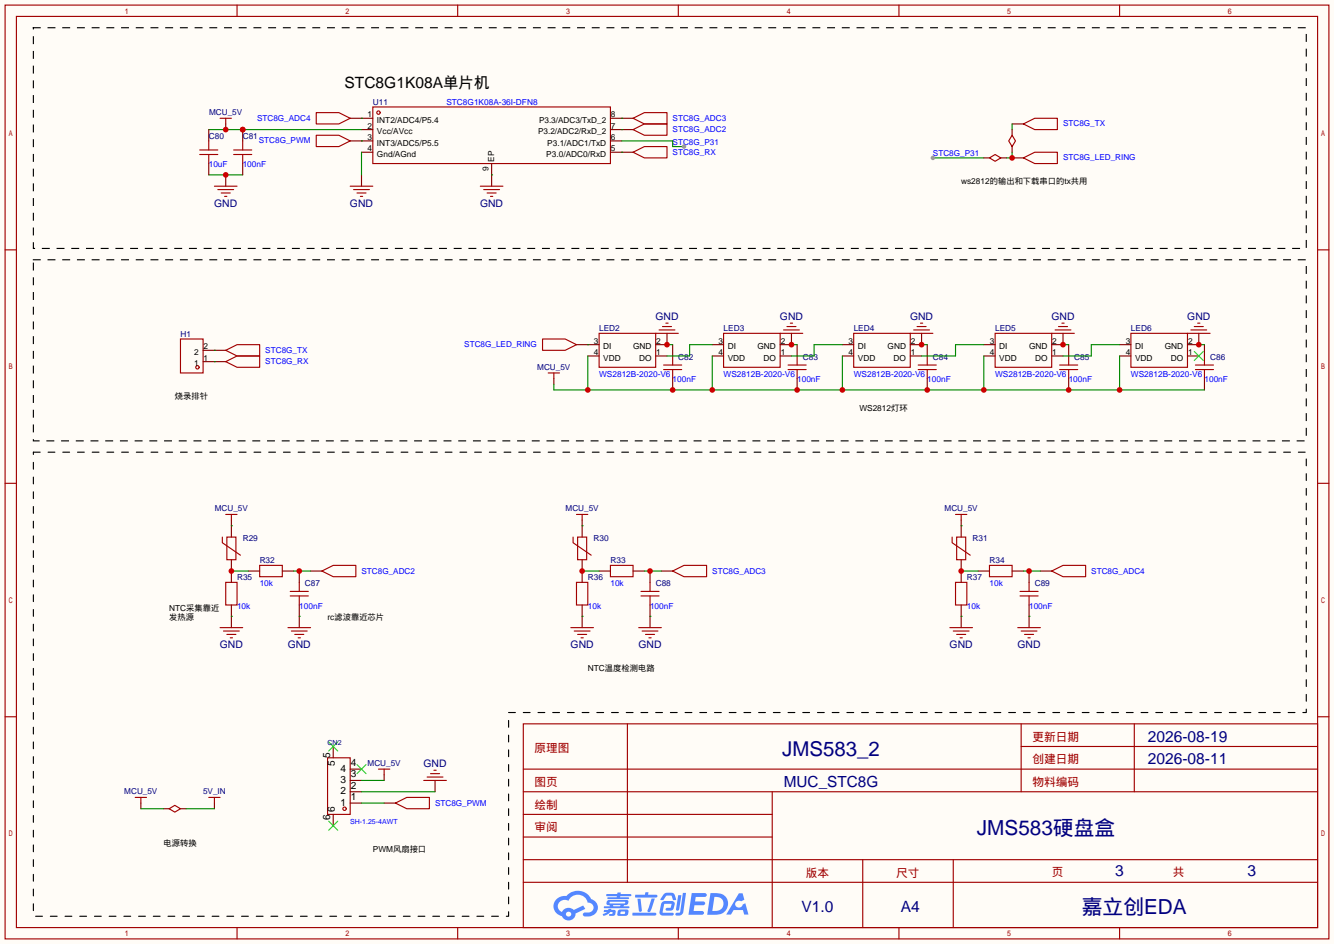
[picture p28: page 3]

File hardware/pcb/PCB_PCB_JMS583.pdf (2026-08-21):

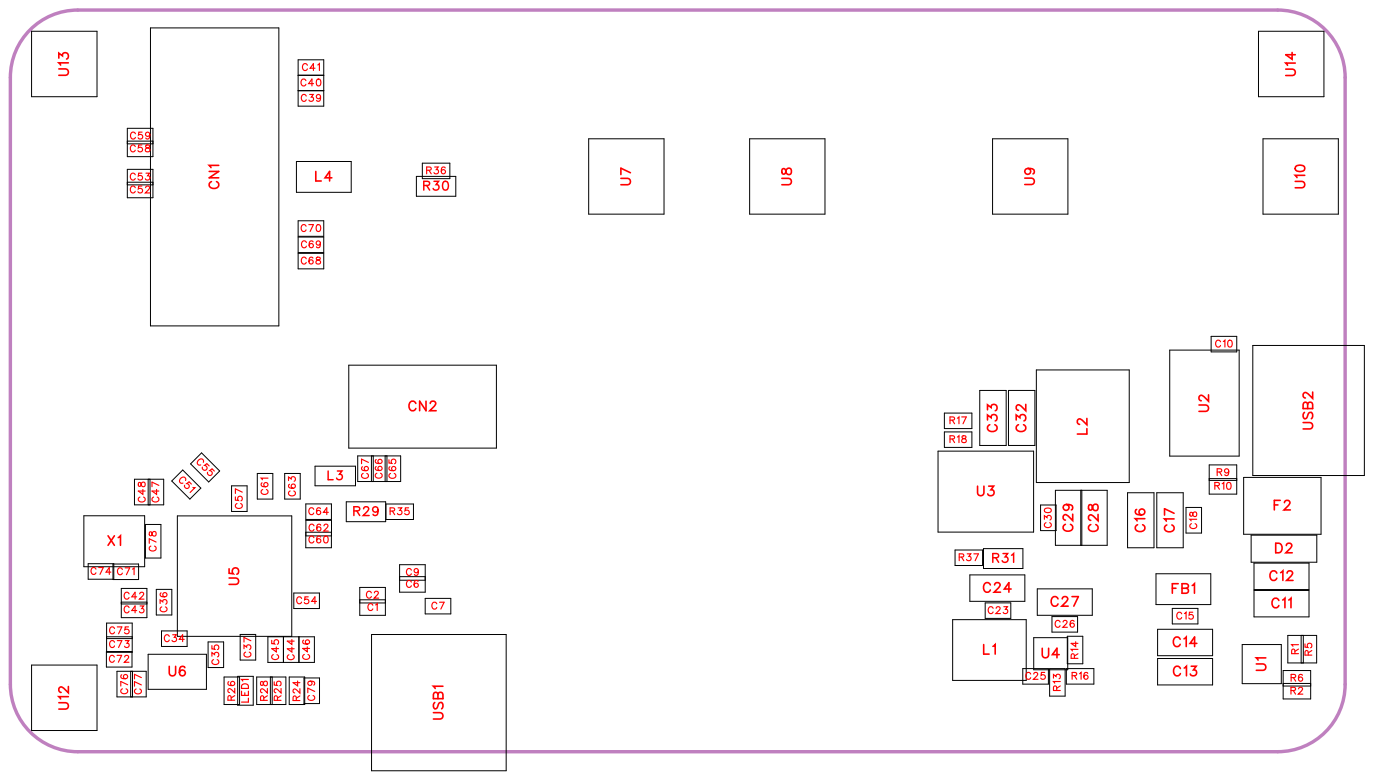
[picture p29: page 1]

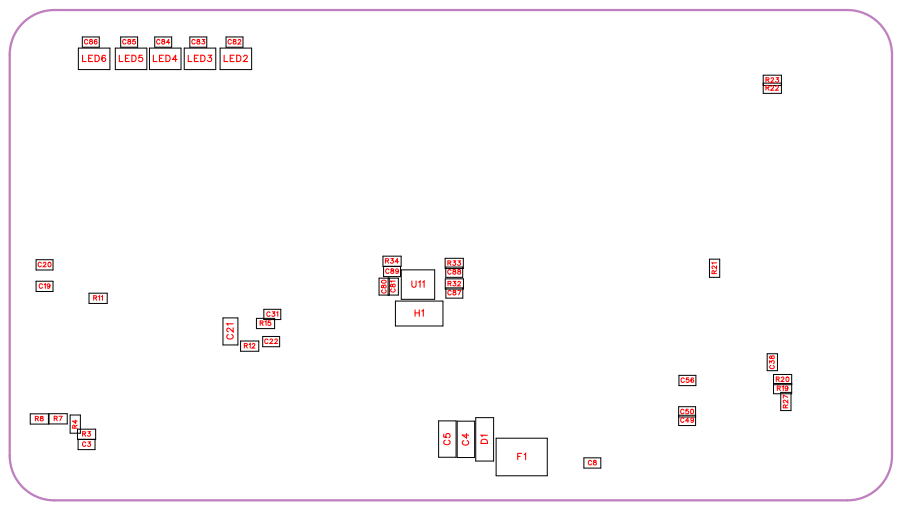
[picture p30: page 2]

No. | Quantity | Comment | Designator | Footprint | Value | Manufacturer Part | Manufacturer | Supplier Part | Supplier
1 | 45 | 100nF | C1,C2,C3,C6,C9,C15,C18, C22,C23,C26,C30,C34,C35 ,C36,C37,C38,C41,C42,C4 6,C48,C50,C51,C54,C55,C 56,C57,C60,C61,C62,C63, C64,C67,C70,C74,C75,C77 ,C81,C82,C83,C84,C85,C8 6,C87,C88,C89 | C0402 | 100nF | HGC0402R5 106M100NT EJ | Chinocera( 华 ) 瓷 | | LCSC
2 | 6 | 22uF | C4,C11,C13,C16,C32,C33 | C0805 | 22uF | HGC0805R5 226M350NS LJ | Chinocera( 华 瓷 ) | C22367832 | LCSC
3 | 8 | 10uF | C5,C12,C14,C17,C24,C27, C28,C29 | C0805 | 10uF | HGC0805R5 226M350NS LJ | Chinocera( 华 瓷 ) | | LCSC
4 | 4 | 330pF | C7,C8,C19,C20 | C0402 | 330pF | HGC0402R5 106M100NT EJ | Chinocera( 华 瓷 ) | | LCSC
5 | 10 | 1uF | C10,C40,C43,C44,C47,C49 ,C66,C69,C73,C79 | C0402 | 1uF | HGC0402R5 106M100NT EJ | Chinocera( 华 瓷 ) | | LCSC
6 | 1 | 10nF | C21 | C0603 | 10nF | HGC0603R5 106M350NT HJ | Chinocera( 华 瓷 ) | | LCSC
7 | 1 | 22pF | C25 | C0402 | 22pF | HGC0402R5 106M100NT EJ | Chinocera( 华 瓷 ) | | LCSC
8 | 1 | 3.9nF | C31 | C0402 | 3.9nF | HGC0402R5 106M100NT EJ | Chinocera( 华 ) 瓷 | | LCSC
9 | 8 | 10uF | C39,C45,C65,C68,C71,C72 ,C76,C80 | C0402 | 10uF | HGC0402R5 106M100NT EJ | Chinocera( 华 ) 瓷 | | LCSC
10 | 4 | 220nF | C52,C53,C58,C59 | C0402 | 220nF | HGC0402R5 106M100NT EJ | Chinocera( 华 ) 瓷 | | LCSC
11 | 1 | 15pF | C78 | C0402 | 15pF | CC0402JRN PO9BN200 | YAGEO(国巨 ) | | LCSC
12 | 1 | 91302-32-06 7RDM | CN1 | CONN-SMD_ 91302-32-06 7RDM | | 91302-32-06 7RDM | UMaxconn( 友贸 ) | C1509730 | LCSC
13 | 1 | SH-1.25-4A WT | CN2 | CONN-SMD_ SH-1.25-4A WT | | SH-1.25-4A WT | 深海电子 | C53260987 | LCSC
14 | 2 | SMF5.0CA | D1,D2 | SOD-123FL_ L2.7-W1.8-L S3.8-BI | | SMF5.0CA | R+O(宏嘉诚 ) | C19077498 | LCSC
15 | 2 | SMD1812-30 0-12 | F1,F2 | F1812 | | SMD1812-30 0-12 | R+O(宏嘉诚 ) | C46641166 | LCSC
16 | 1 | BLM21PG30 0SN1D | FB1 | L0805 | 30 | BLM21PG30 0SN1D | muRata(村田 ) | C16903 | LCSC

17 | 1 | A2541WV-2P | H1 | HDR-TH_P2. 54-H-M_A25 41WV-2P | | A2541WV-2P | CJT(长江连 接器 ) | C225477 | LCSC
18 | 1 | 2.2uH | L1 | IND-SMD_L4 .4-W4.2 | 2.2uH | FXL0420-2R 2-M | cjiang(长江微 电) | C167206 | LCSC
19 | 1 | 10uH | L2 | IND-SMD_L7 .3-W6.8 | 10uH | FXL0630-100 -M | cjiang(长江微 电) | C167223 | LCSC
20 | 1 | CBM160808 U121T | L3 | L0603 | | CBM160808 U121T | FH(风华 ) | C62708 | LCSC
21 | 1 | CBM201209 U121T | L4 | L0805 | | CBM201209 U121T | FH(风华 ) | C93624 | LCSC
22 | 1 | NCD0402G1 | LED1 | LED-SMD_L 1.0-W0.5_FC -F1005UGK | | NCD0402G1 | 国星光电 | C130723 | LCSC
23 | 5 | WS2812B-20 20-V6 | LED2,LED3,LED4,LED5,LE D6 | LED-SMD_4 P-L2.2-W2.0-P1.00_WS28 15C-2020-4P | | WS2812B-20 20-V6 | worldsemi | C52917434 | LCSC
24 | 2 | 20k | R1,R2 | R0402 | 20k | THC02H100 2BT | FH(风华 ) | | LCSC
25 | 1 | 29.8k | R3 | R0402 | 29.8k | THC02H100 2BT | FH(风华 ) | | LCSC
26 | 5 | 100k | R4,R11,R12,R14,R25 | R0402 | 100k | THC02H100 2BT | FH(风华 ) | | LCSC
27 | 3 | 5k | R5,R6,R8 | R0402 | 5k | THC02H100 2BT | FH(风华 ) | | LCSC
28 | 9 | 10k | R7,R18,R20,R32,R33,R34, R35,R36,R37 | R0402 | 10k | THC02H100 2BT | FH(风华 ) | | LCSC
29 | 2 | 2k | R9,R10 | R0402 | 2k | THC02H100 2BT | FH(风华 ) | | LCSC
30 | 1 | 91k | R13 | R0402 | 91k | THC02H100 2BT | FH(风华 ) | | LCSC
31 | 1 | 6.8k | R15 | R0402 | 6.8k | THC02H100 2BT | FH(风华 ) | | LCSC
32 | 1 | 120k | R16 | R0402 | 120k | THC02H100 2BT | FH(风华 ) | | LCSC
33 | 1 | 26.1k | R17 | R0402 | 26.1k | THC02H100 2BT | FH(风华 ) | | LCSC
34 | 1 | 5.1k | R19 | R0402 | 5.1k | THC02H100 2BT | FH(风华 ) | | LCSC
35 | 1 | 12k | R21 | R0402 | 12k | THC02H100 2BT | FH(风华 ) | | LCSC
36 | 2 | 49.9 | R22,R23 | R0402 | 49.9 | THC02H100 2BT | FH(风华 ) | | LCSC
37 | 1 | 510k | R24 | R0402 | 510k | THC02H100 2BT | FH(风华 ) | | LCSC
38 | 1 | 200 | R26 | R0402 | 200 | THC02H100 2BT | FH(风华 ) | | LCSC
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

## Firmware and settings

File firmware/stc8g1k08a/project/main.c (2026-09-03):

#include <STC8G.H>
#include "stc8g_gpio.h"
#include "stc8g_uart.h"
#include "stc8g_delay.h"
#include "stc8g_adc.h"
#include "stc8g_timer_pwm.h"  
#include "stc8g_ws2812.h"

/* ================= 用户配置：温度-转速曲线 ================= */
#define TEMP_LOW     25    /* 低于 25.0℃：风扇停转 */
#define TEMP_HIGH    60    /* 高于 60.0℃：风扇满速 */
#define HYSTERESIS   2     /* 2.0℃ 滞回，防止临界点频繁启停 */


/* 三路权重（与 stc8g_adc.h 中 TEMP_WEIGHT 保持一致，仅用于打印说明） */

/**
 * @brief 根据平均温度计算并设置风扇 PWM
 * @param  avg_temp: 加权平均温度 (0.1℃)
 */
static void Fan_Update(int avg_temp)
{
    static unsigned char last_duty = 0;
    unsigned char target;

    if (avg_temp < TEMP_LOW) {
        target = 0;
    } else if (avg_temp >= TEMP_HIGH) {
        target = 100;
    } else {
        /* 线性：25~60℃ 对应 0%~100% */
        target = (unsigned char)((avg_temp - TEMP_LOW) * 100L / (TEMP_HIGH - TEMP_LOW));
    }

    /* 迟滞：只有变化超过HYSTERESIS时才更新 */
    if (target > last_duty + HYSTERESIS) {
        last_duty = target;
    } else if (target + HYSTERESIS < last_duty) {
        last_duty = target;
    }
    timer0_pwm_setduty(last_duty);   
}

void main(void)
{
    int temps[3];
    int avg_temp;

    // 1. GPIO 初始化
    stc8g_gpio_init(3, 0, 2);  // P3.0 RXD
    stc8g_gpio_init(3, 1, 1);  // P3.1 TXD
    stc8g_gpio_init(3, 2, 2);  // P3.2 ADC 输入
    stc8g_gpio_init(3, 3, 2);  // P3.3 ADC 输入
    stc8g_gpio_init(5, 4, 2);  // P5.4 ADC 输入

    // 2. 串口初始化
    //UartInit();

    // 3. ADC 初始化
	ADCInit();  // 仅一次

    // 4. 校准参考电压（可选）
    //int vref = adcreference();

    // 5. PWM 初始化
    timer0_pwm_init(5, 5);		// P5.5 PWM 输出
    timer0_pwm_setfreq(21600);
    timer0_pwm_setduty(50);
    timer0_pwm_enable(1);
	
	// 6.ws2812呼吸灯初始化
	ws2812_init();

    ES = 1;
    EA = 1;
	
	
    while(1)
    {
        // 采集温度并获取加权平均
        avg_temp = ADC_SampleTemperatures(temps);

        // 根据温度设置 PWM
        Fan_Update(avg_temp);
		
		// 更新 WS2812 灯效
		ws2812_update_by_temp(avg_temp);

        delay_ms(1);
    }
}

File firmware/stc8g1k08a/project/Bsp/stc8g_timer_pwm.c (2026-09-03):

#include "stc8g_timer_pwm.h"

// 静态变量：记录当前IO电平（0=低，1=高）
static volatile unsigned char pwm_current_level = 0;

// PWM全局配置（volatile防止编译器优化，中断里用的变量必须加）
volatile unsigned char pwm_duty = 50;    // 占空比0~100%
volatile unsigned int pwm_freq = 21600; // PWM频率，默认21.6kHz（适配4线风扇）
volatile bit pwm_en = 0;                 // PWM使能开关

// 定时器0初值缓存（双缓冲，避免中断里改值产生毛刺）
volatile unsigned int pwm_high_th = 0;  // 高电平定时初值（高8位）
volatile unsigned int pwm_high_tl = 0;  // 高电平定时初值（低8位）
volatile unsigned int pwm_low_th = 0;   // 低电平定时初值（高8位）
volatile unsigned int pwm_low_tl = 0;   // 低电平定时初值（低8位）

/**
 * 定时器0 PWM初始化
 * 配置：16位模式，1分频（11.0592MHz计数频率），开中断
 */
void timer0_pwm_init(unsigned char pwm_port, unsigned char pwm_pin)
{
    // 1. IO配置：推挽输出（和你之前的stc8g_gpio_init一致）
    stc8g_gpio_init(pwm_port, pwm_pin, 1);
	P55=0;
	
    // 2. 定时器模式配置：模式1（16位定时器，不自动重装）
    TMOD &= 0xF0; // 清定时器0的模式位（高4位留给定时器1）
    TMOD |= 0x01; // M1=0, M0=1 → 模式1

    // 3. 分频配置：1分频（11.0592MHz计数频率，对应PCA的1T模式）
    AUXR |= 0x80;  // T0x12=1 → 1分频，计数周期=1/11.0592M≈0.0904us
    // 如果要12分频（和传统8051一致），改成 AUXR &= ~0x80;

    // 4. 初始频率/占空比计算（默认21.6kHz，50%占空比）
    timer0_pwm_setfreq(pwm_freq);
    timer0_pwm_setduty(pwm_duty);

    // 5. 中断配置
    ET0 = 1; // 开定时器0中断
    EA  = 1; // 开总中断

    // 6. 默认不启动，等enable后再开
    TR0 = 0;
}

/**
 * 设置PWM频率（Hz）
 * 公式推导：
 * 计数频率 f_count = 11.0592MHz / 分频系数（这里分频=1）
 * 计数周期 t_count = 1 / f_count ≈ 0.0904us
 * PWM周期 T = 1/freq
 * 高电平时间 t_high = T * duty/100
 * 低电平时间 t_low = T * (100-duty)/100
 * 高电平计数次数 N_high = t_high / t_count
 * 低电平计数次数 N_low = t_low / t_count
 * 定时初值 = 65536 - 计数次数
 */
void timer0_pwm_setfreq(unsigned int freq)
{
    unsigned long period_us;      // PWM周期（微秒）
    unsigned long high_us, low_us; // 高低电平持续时间（微秒）
    unsigned int high_cnt, low_cnt; // 高低电平计数次数
    unsigned int duty = pwm_duty; // 读取当前占空比

    if(freq == 0) freq = 1; // 防止除零
    period_us = 1000000UL / freq; // 周期转微秒

    // 计算高低电平时间
    high_us = period_us * duty / 100;
    low_us  = period_us * (100 - duty) / 100;

    // 转成计数次数（1分频下，计数周期≈0.0904us）
    high_cnt = (unsigned int)(high_us / 0.090422455); // 1/11.0592e6 *1e6
    low_cnt  = (unsigned int)(low_us  / 0.090422455);


    // 双缓冲：先计算好初值，再赋值给全局变量，避免中断里读到半成品
    pwm_high_th = (65536 - high_cnt) >> 8; // 高8位
    pwm_high_tl = (65536 - high_cnt) & 0xFF; // 低8位
    pwm_low_th  = (65536 - low_cnt) >> 8;
    pwm_low_tl  = (65536 - low_cnt) & 0xFF;
}

/**
 * 设置占空比（0~100%）
 * 双缓冲逻辑：只改占空比变量，下次setfreq时自动生效，避免毛刺
 */
void timer0_pwm_setduty(unsigned char duty)
{
	//软件翻转IO的方式做不到绝对的0%/100%，必须关定时器直接拉IO，不然哪怕计数设成0，中断触发一次也会出窄脉冲。
    if(duty > 100) duty = 100;
    pwm_duty = duty;
    
    // ? 新增：0%占空比，直接关定时器+拉低IO
    if(duty == 0) {
        timer0_pwm_enable(0);
        return;
    }
    // ? 新增：100%占空比，直接关定时器+拉高IO
    if(duty >= 100) {
        timer0_pwm_enable(0);
        stc8g_gpio_set_level(3, 3, 1); // 直接拉高，不用定时器翻转
        return;
    }
    
    // 正常占空比才重新计算参数
    timer0_pwm_setfreq(pwm_freq);
    timer0_pwm_enable(1);
}

/**
 * 使能/失能PWM
 */
void timer0_pwm_enable(bit en)
{
    pwm_en = en;
    if(en) {
        // 启动时默认输出低电平，加载低电平初值
        pwm_current_level = 0;
        P33=0;
        TH0 = pwm_low_th;
        TL0 = pwm_low_tl;
        TR0 = 1; // 启动定时器0
    } else {
        TR0 = 0; // 停止定时器0
        P33=0; // 输出低电平
    }
}

/**
 * 定时器0中断服务函数
 * 核心逻辑：每次溢出翻转IO，重装对应电平的初值
 * 中断里只做最简操作，不耗时，符合你之前学的“中断快进快出”原则
 */
void Timer0_ISR(void) interrupt 1
{
    if(pwm_en == 0) return; // PWM未使能，直接退出

    if(pwm_current_level == 0) {
        // 当前是低电平，翻转为高电平，重装高电平初值
        TH0 = pwm_high_th;
        TL0 = pwm_high_tl;
		pwm_current_level = 1;
        P55=1;
    } else {
        // 当前是高电平，翻转为低电平，重装低电平初值
        TH0 = pwm_low_th;
        TL0 = pwm_low_tl;
		pwm_current_level = 0;
        P55=0;
    }
}

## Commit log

2026-03-30 删除文件 README.en.md
2026-03-30 整理文件
    [BOM_jms583.csv]
2026-08-23 更新原理图、pcb、外壳
    [3007涡轮风扇模型.step, BOM_JMS583硬盘盒.csv, JMS583硬盘盒外壳.f3z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]
2026-08-23 更新BOM表
    [BOM_JMS583硬盘盒.csv, BOM_JMS583硬盘盒.xlsx]
2026-09-03 更新assets以及enclosure
    [BOM_JMS583硬盘盒.xlsx, JMS583硬盘盒外壳.f3z, 下壳.stl]
2026-09-03 更新固件和windows的测试
    [STARTUP.obj, main.obj, stc8g_adc.obj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]
2026-09-06 更新风扇固件，狂暴模式
    [STARTUP.obj, main.obj, stc8g_adc.obj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]

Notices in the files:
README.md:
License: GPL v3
